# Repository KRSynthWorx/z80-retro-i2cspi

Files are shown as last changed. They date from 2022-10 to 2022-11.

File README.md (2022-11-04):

# [Z80-Retro!](https://github.com/johnwinans/2063-Z80) I2C/SPI Master Interface Board & Driver Library

An addon I2C/SPI master interface board that uses the [Z80-Retro!](https://github.com/johnwinans/2063-Z80)
parallel printer port and a bit-banged driver library to interact
with the I2C/SPI ports. KiCad design files are also included.

## Description

### Driver Library
[i2cspi_lib.asm](src/i2cspi_lib.asm) -
This driver library includes all necessary routines to communicate with I2C and SPI hardware devices
using the Z80-Retro! parallel port. Extensive comments and protocol descriptions are provided
to help understand the library. The library requires the [retromon.sym](https://github.com/KRSynthWorx/z80-retro-monitor/blob/main/src/retromon.sym)
symbol table from the [z80-retro-monitor](https://github.com/KRSynthWorx/z80-retro-monitor) project.

### PCB Hardware
An I2C/SPI master interface board using bit-bang techniques and utilizes the Z80-Retro!
parallel printer port. The PCB design includes 4 I2C ports and 4 SPI ports. The I2C
ports are all common and the SPI ports include 4 individual chip select (CS) lines.
Requires +5vdc be connected from the Z80-Retro! or an external power supply.

* A PDF version of the schematic can be found [here](kicad/i2c-adapter-schematic.pdf).

### PCB Layout

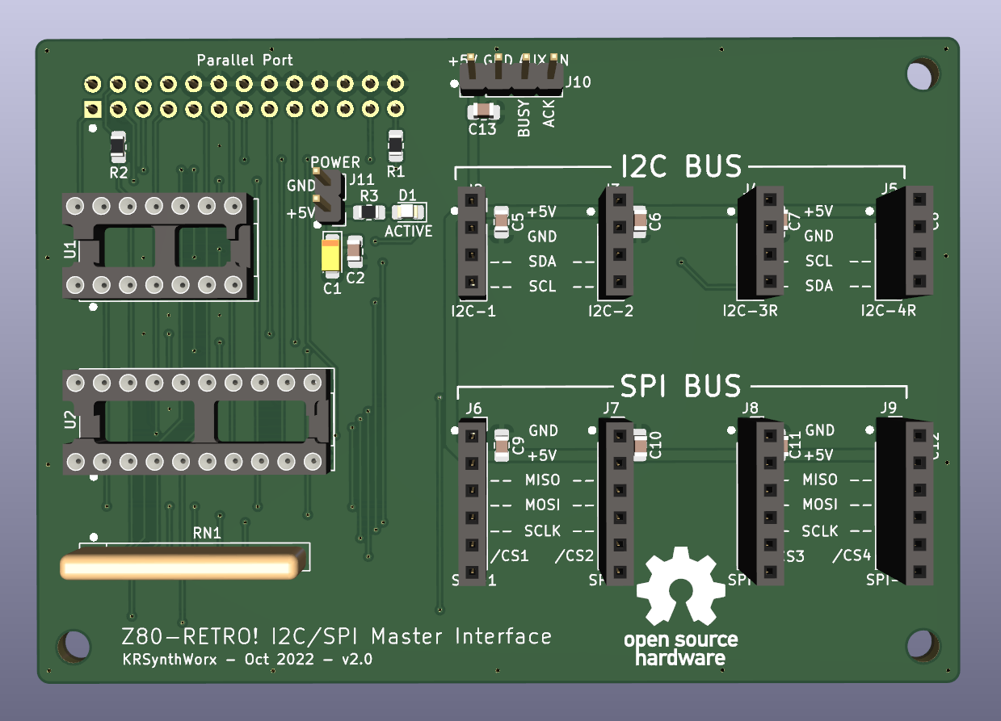
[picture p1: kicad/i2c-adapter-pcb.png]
PC Board Image I2C/SPI Master Interface Board


---

### I2C Timing Capture

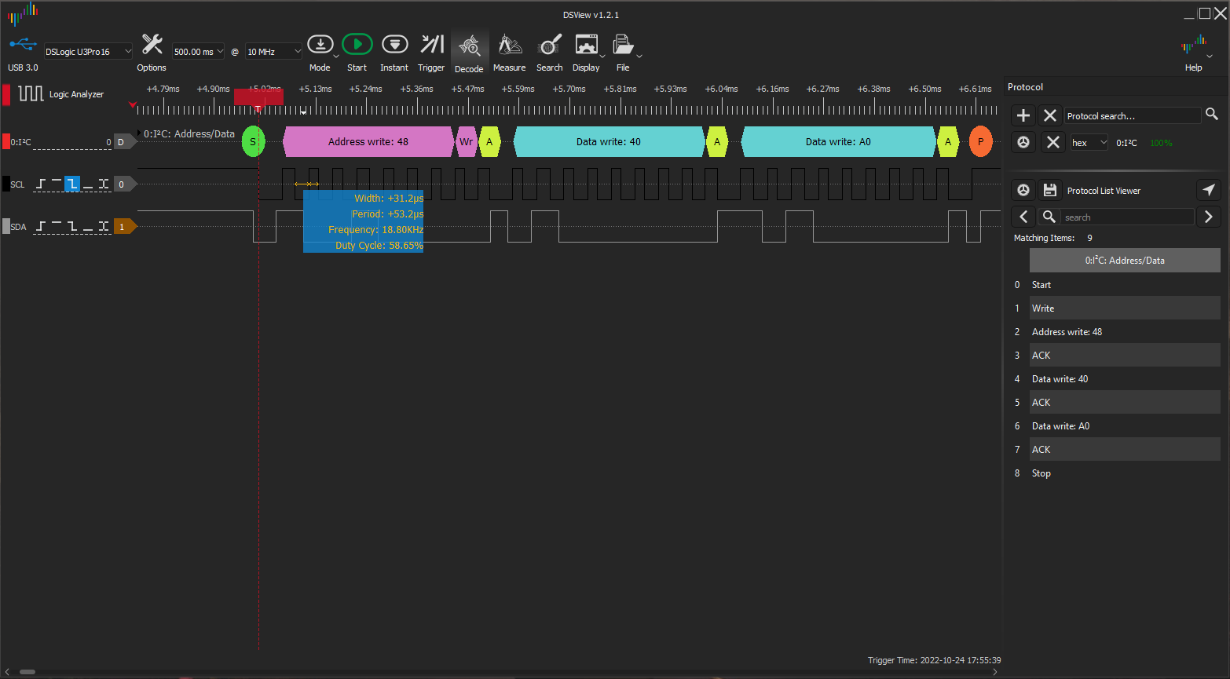
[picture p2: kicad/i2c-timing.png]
I2C Timing I2C Logic Analyzer Write Timing


---

### SPI Timing Capture
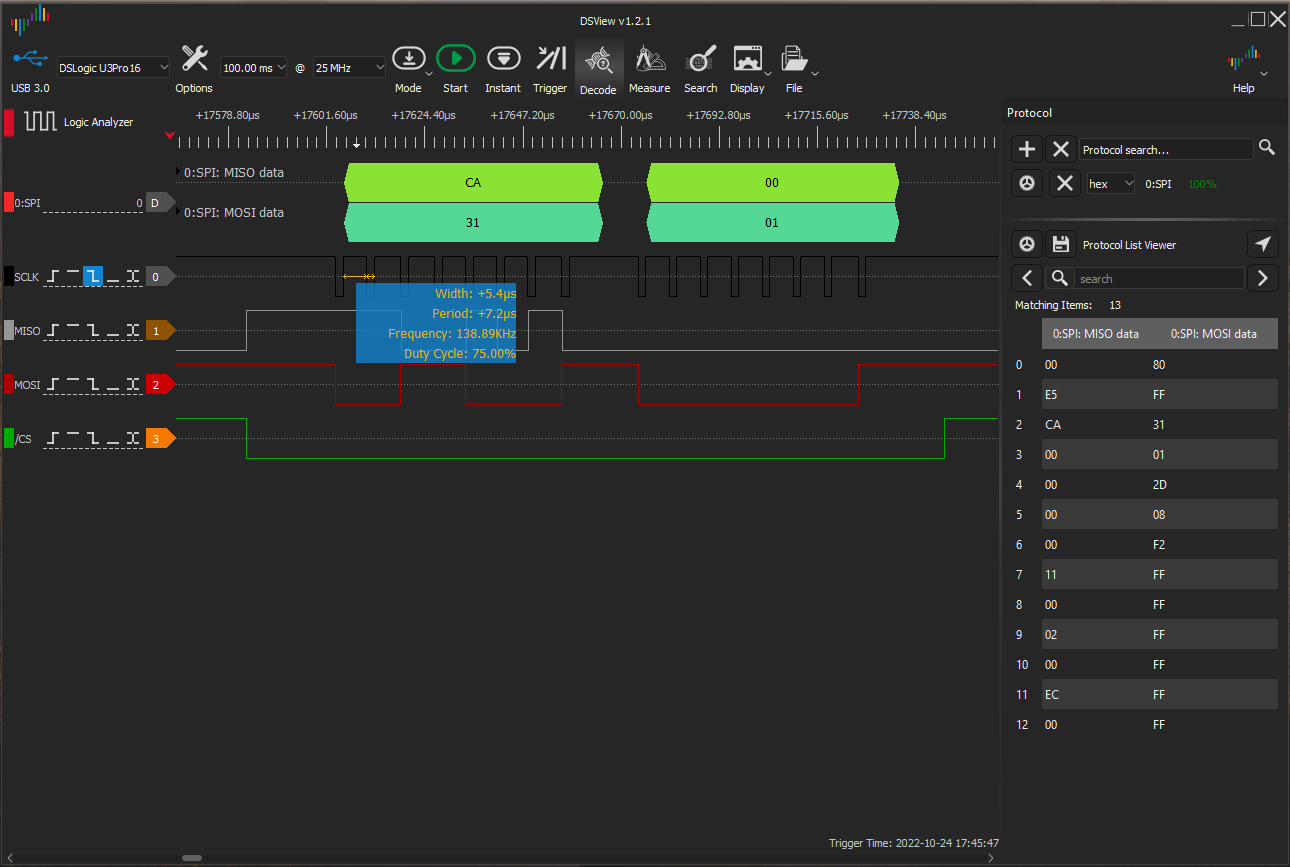
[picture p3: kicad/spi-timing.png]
SPI Timing SPI Logic Analyzer Write Timing


## Help

### Library Common Routines

```ACTIVE_LED``` - Set the ACTIVE LED on the I2C/SPI interface board on or off  

---

### I2C Routines

```I2C_INIT``` - Initialize I2C status variables and the Z80-Retro! PRN_DAT port  
```I2C_START``` - Initiate I2C communication with a START condition  
```I2C_STOP``` - Stop I2C communication with a STOP condition  
```I2C_SEND_BIT``` - Send a bit over the I2C bus  
```I2C_READ_BIT``` - Read a bit on the I2C bus  
```I2C_SEND_BYTE``` - Send a byte to the I2C bus  
```I2C_READ_BYTE``` - Read a byte from the I2C bus  
```I2C_SEND_STREAM``` - Send a byte stream to the I2C bus  
```I2C_READ_STREAM``` - Read a byte stream from the I2C bus  

---

### SPI Routines

```SPI_INIT```- Initialize the SPI MODE, bit transfer order and the Z80-Retro! PRN_DAT port  
```SPI_SEND_BYTE``` - Send 8 bits to the SPI port and discard the received data  
```SPI_READ_BYTE``` - Read 8 bits from the SPI port  
```SPI_CSx_TRUE``` - Assert the select line initialized in SPI_INIT (CS1 - CS4) supported  
```SPI_CSx_FALSE``` - De-assert the select line initialized in SPI_INIT (CS1 - CS4) supported  
```SPI_SEND_STREAM``` - Send a stream of bytes to the SPI port  
```SPI_READ_STREAM``` - Read a stream of bytes from the SPI port  

---

Several example routines are included to test the various functions. Everything is heavily
commented explaining the library routines and how to use them. These include:
- [ad_test.asm](src/ad_test.asm) - test a NXP Semiconductors PCF8591 I2C A/D-D/A converter
- [eeprom_test.asm](src/eeprom_test.asm) - test a generic 24C256 I2C EEPROM
- [gpio_test.asm](src/gpio_test.asm) - test a NXP Semiconductors PCF8574 I2C 8-bit GPIO expander
- [led_test.asm](src/led_test.asm) - test an Analog Devices MAX7219 LED driver in SPI mode 0
- [oled_test.asm](src/oled_test.asm) - test a generic SSD1306 128x64 SPI 0.96" OLED display
- [spi_test.asm](src/spi_test.asm) - test an Analog Devices ADXL345 accelerometer in SPI mode 3

## Author

[Kenny Maytum](mailto:ken_m@comcast.net) - KRSynthWorx

## Version History

* v1.0 - Driver Library
	* Initial Public Release
* v2.0 - KiCad Design Files
	* Initial Public Release

## License

This project is licensed under the [GNU Lesser General Public License] - see the LICENSE file for details

## Acknowledgments

Inspiration, code snippets, libraries, etc.
* [John's Basement YouTube Channel](https://www.youtube.com/c/JohnsBasement)
* [John Winans](https://github.com/johnwinans)
* [K. S. Jiang](https://github.com/ksjiang/bb85)
* [I2C Bus](https://i2c-bus.org)
* [SPI Bus](https://www.corelis.com/education/tutorials/spi-tutorial)

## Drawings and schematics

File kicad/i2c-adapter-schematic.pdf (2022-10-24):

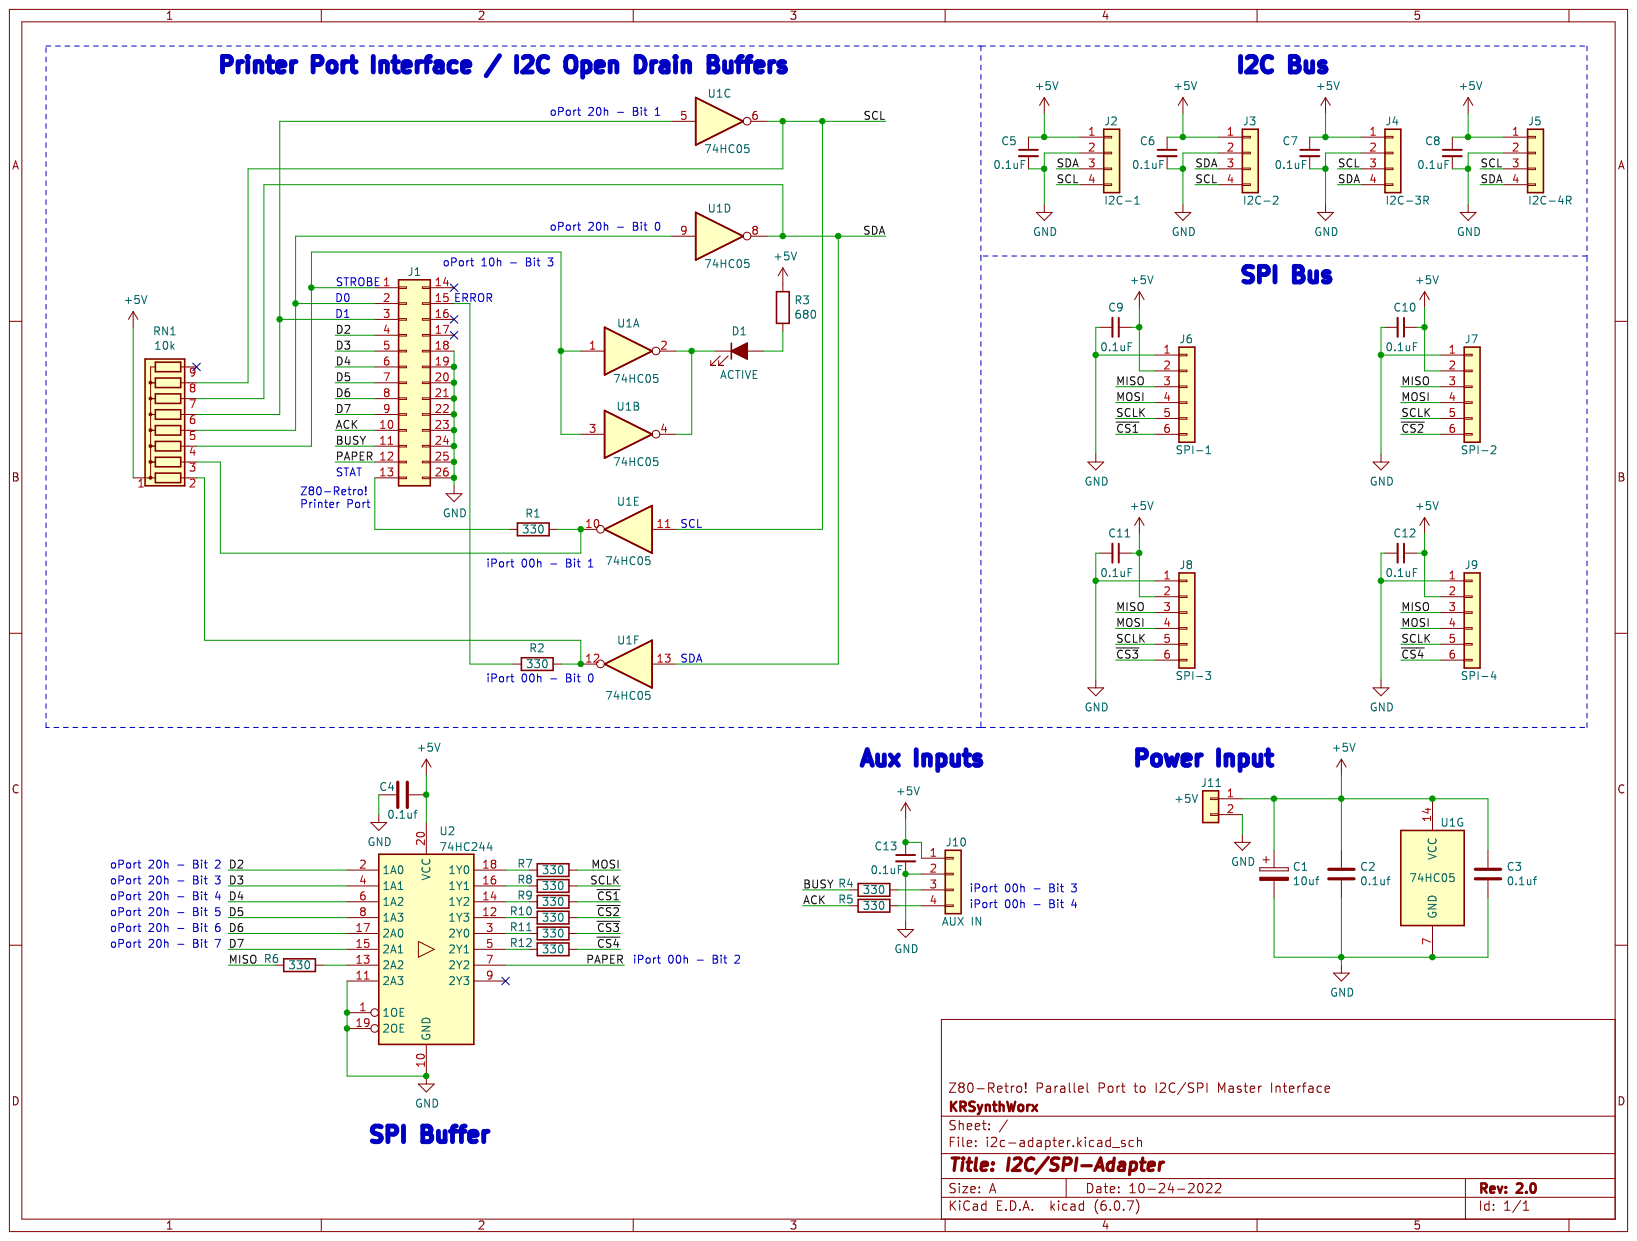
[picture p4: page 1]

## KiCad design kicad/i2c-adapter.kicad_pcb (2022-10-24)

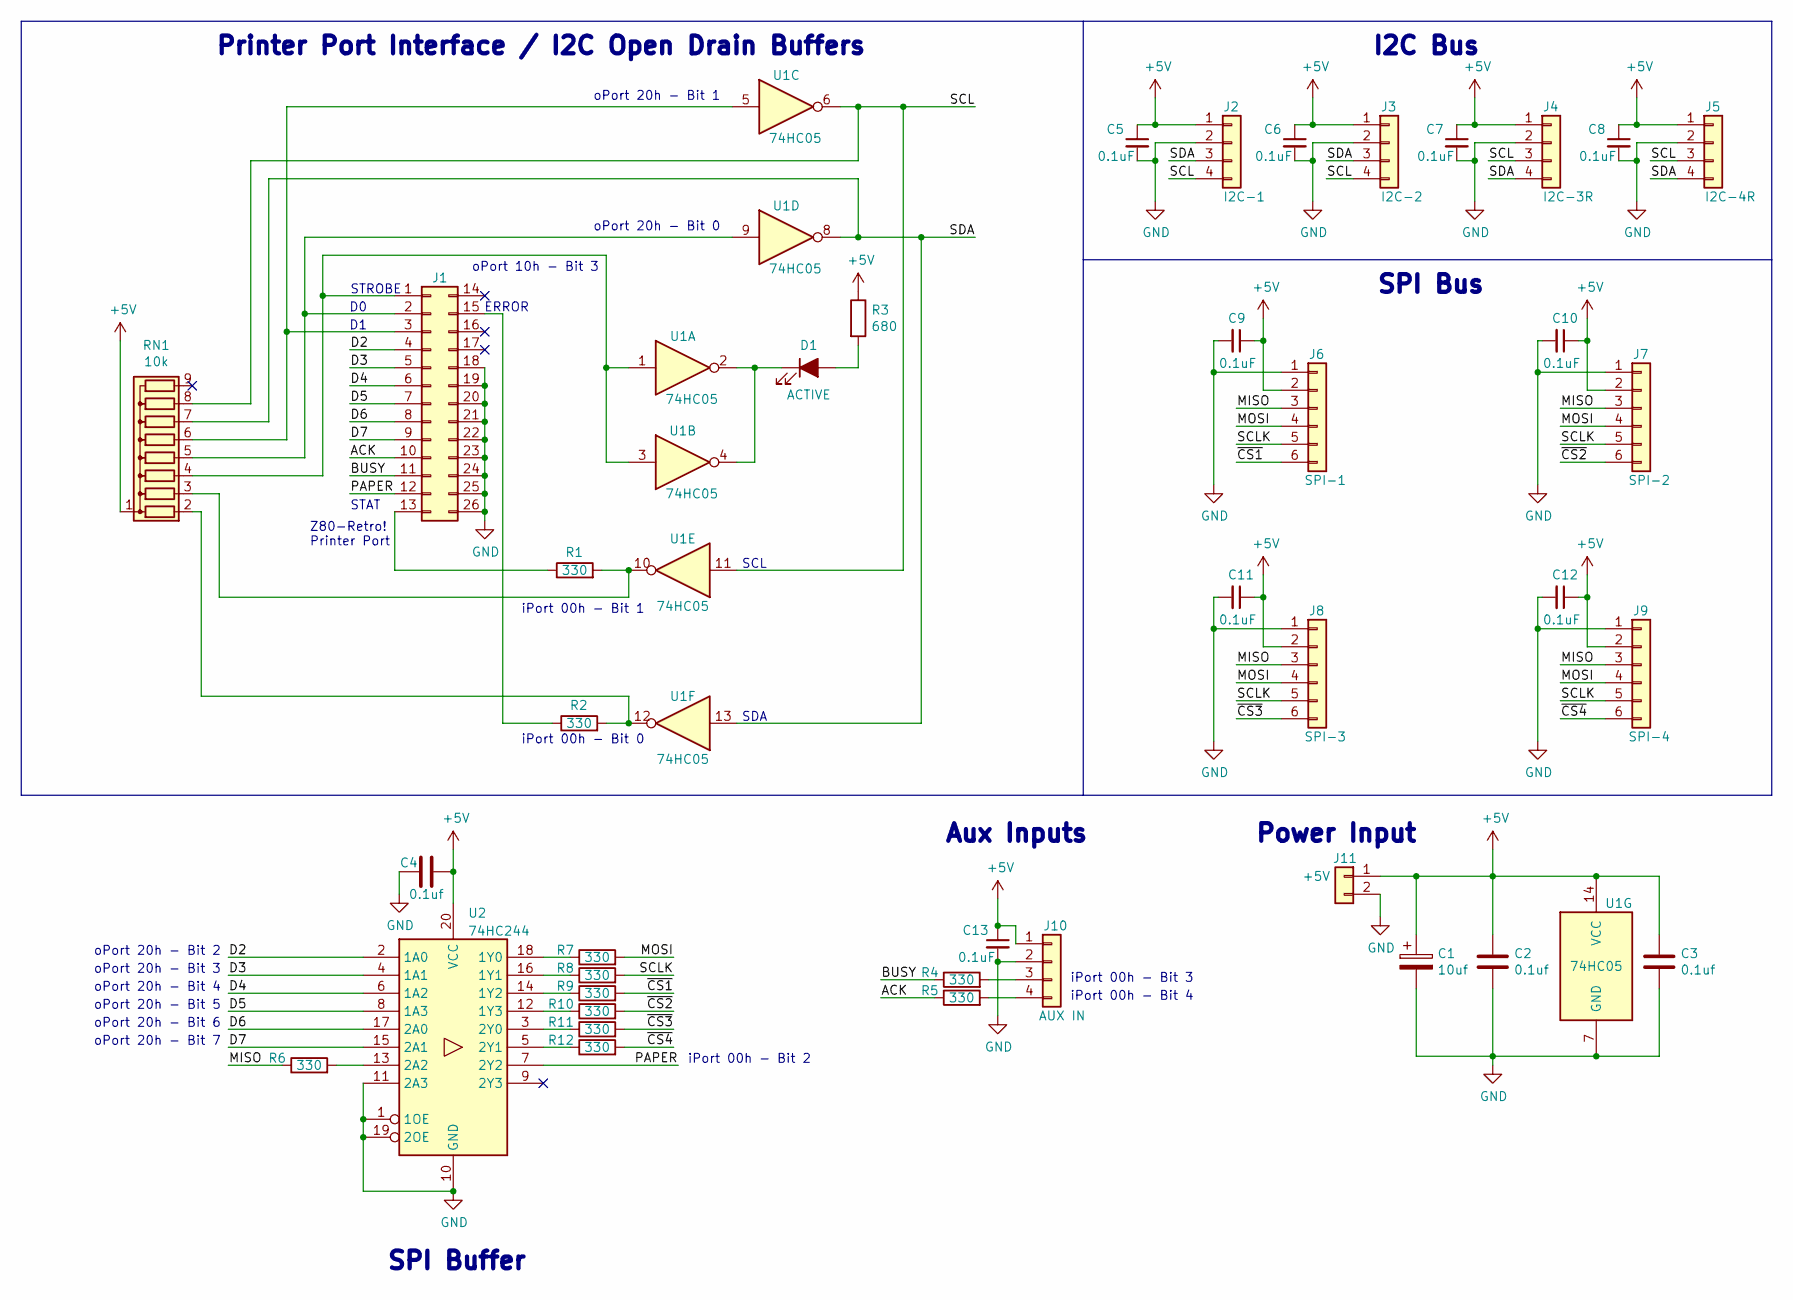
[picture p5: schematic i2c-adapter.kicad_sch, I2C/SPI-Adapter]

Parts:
C1: 10uf; CP_EIA-3216-10_Kemet-I_Pad1.58x1.35mm_HandSolder
C2, C3, C4: 0.1uf; C_0805_2012Metric_Pad1.18x1.45mm_HandSolder
C5, C6, C7, C8, C9, C10, C11, C12, C13: 0.1uF; C_0805_2012Metric_Pad1.18x1.45mm_HandSolder
D1: ACTIVE; LED_0805_2012Metric_Pad1.15x1.40mm_HandSolder
J1: Conn_02x13_Top_Bottom; PinSocket_2x13_P2.54mm_Vertical_clockwise
J2: I2C-1; PinSocket_1x04_P2.54mm_Vertical
J3: I2C-2; PinSocket_1x04_P2.54mm_Vertical
J4: I2C-3R; PinSocket_1x04_P2.54mm_Vertical
J5: I2C-4R; PinSocket_1x04_P2.54mm_Vertical
J6: SPI-1; PinSocket_1x06_P2.54mm_Vertical
J7: SPI-2; PinSocket_1x06_P2.54mm_Vertical
J8: SPI-3; PinSocket_1x06_P2.54mm_Vertical
J9: SPI-4; PinSocket_1x06_P2.54mm_Vertical
J10: AUX IN; PinHeader_1x04_P2.54mm_Vertical
J11: +5V; PinHeader_1x02_P2.54mm_Vertical
R1, R2, R4, R5, R6, R7, R8, R9, R10, R11, R12: 330; R_0805_2012Metric_Pad1.20x1.40mm_HandSolder
R3: 680; R_0805_2012Metric_Pad1.20x1.40mm_HandSolder
RN1: 10k; R_Array_SIP9
U1: 74HC05; DIP-14_W7.62mm_Socket
U2: 74HC244; DIP-20_W7.62mm_Socket

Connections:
+5V: C1.1, C2.1, C3.1, C4.1, C5.1, C6.1, C7.1, C8.1, C9.1, C10.1, C11.1, C12.1, C13.1, J2.1, J3.1, J4.1, J5.1, J6.2, J7.2, J8.2, J9.2, J10.1, J11.1, R3.1, RN1.1 (common), U1.14 (VCC), U2.20 (VCC)
/ACK: J1.10, R5.1
/BUSY: J1.11, R4.1
/D2: J1.4, U2.2 (1A0)
/D3: J1.5, U2.4 (1A1)
/D4: J1.6, U2.6 (1A2)
/D5: J1.7, U2.8 (1A3)
/D6: J1.8, U2.17 (2A0)
/D7: J1.9, U2.15 (2A1)
/MISO: J6.3, J7.3, J8.3, J9.3, R6.1
/MOSI: J6.4, J7.4, J8.4, J9.4, R7.2
/PAPER: J1.12, U2.7 (2Y2)
/SCL: J2.4, J3.4, J4.3, J5.3, RN1.8 (R7), U1.6, U1.11
/SCLK: J6.5, J7.5, J8.5, J9.5, R8.2
/SDA: J2.3, J3.3, J4.4, J5.4, RN1.7 (R6), U1.8, U1.13
/~CS1: J6.6, R9.2
/~CS2: J7.6, R10.2
/~CS3: J8.6, R11.2
/~CS4: J9.6, R12.2
GND: C1.2, C2.2, C3.2, C4.2, C5.2, C6.2, C7.2, C8.2, C9.2, C10.2, C11.2, C12.2, C13.2, J1.18, J1.19, J1.20, J1.21, J1.22, J1.23, J1.24, J1.25, J1.26, J2.2, J3.2, J4.2, J5.2, J6.1, J7.1, J8.1, J9.1, J10.2, J11.2, U1.7 (GND), U2.1 (1OE), U2.10 (GND), U2.11 (2A3), U2.19 (2OE)
unnamed: D1.1 (K), U1.2, U1.4
unnamed: D1.2 (A), R3.2
unnamed: J1.1, RN1.4 (R3), U1.1, U1.3
unnamed: J1.2, RN1.5 (R4), U1.9
unnamed: J1.3, RN1.6 (R5), U1.5
unnamed: J1.13, R1.1
unnamed: J1.15, R2.1
unnamed: J10.3, R4.2
unnamed: J10.4, R5.2
unnamed: R1.2, RN1.3 (R2), U1.10
unnamed: R2.2, RN1.2 (R1), U1.12
unnamed: R11.1, U2.3 (2Y0)
unnamed: R12.1, U2.5 (2Y1)
unnamed: R10.1, U2.12 (1Y3)
unnamed: R6.2, U2.13 (2A2)
unnamed: R9.1, U2.14 (1Y2)
unnamed: R8.1, U2.16 (1Y1)
unnamed: R7.1, U2.18 (1Y0)

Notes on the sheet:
iPort 00h - Bit 0
oPort 20h - Bit 3
oPort 20h - Bit 5
oPort 20h - Bit 1
oPort 20h - Bit 0
oPort 10h - Bit 3
Printer Port Interface / I2C Open Drain Buffers
Z80-Retro! Printer Port
oPort 20h - Bit 2
ERROR
oPort 20h - Bit 7
oPort 20h - Bit 6
STAT
I2C Bus
oPort 20h - Bit 4
SCL
Power Input
Aux Inputs
iPort 00h - Bit 4
iPort 00h - Bit 3
iPort 00h - Bit 2
SDA
SPI Bus
STROBE
SPI Buffer
iPort 00h - Bit 1

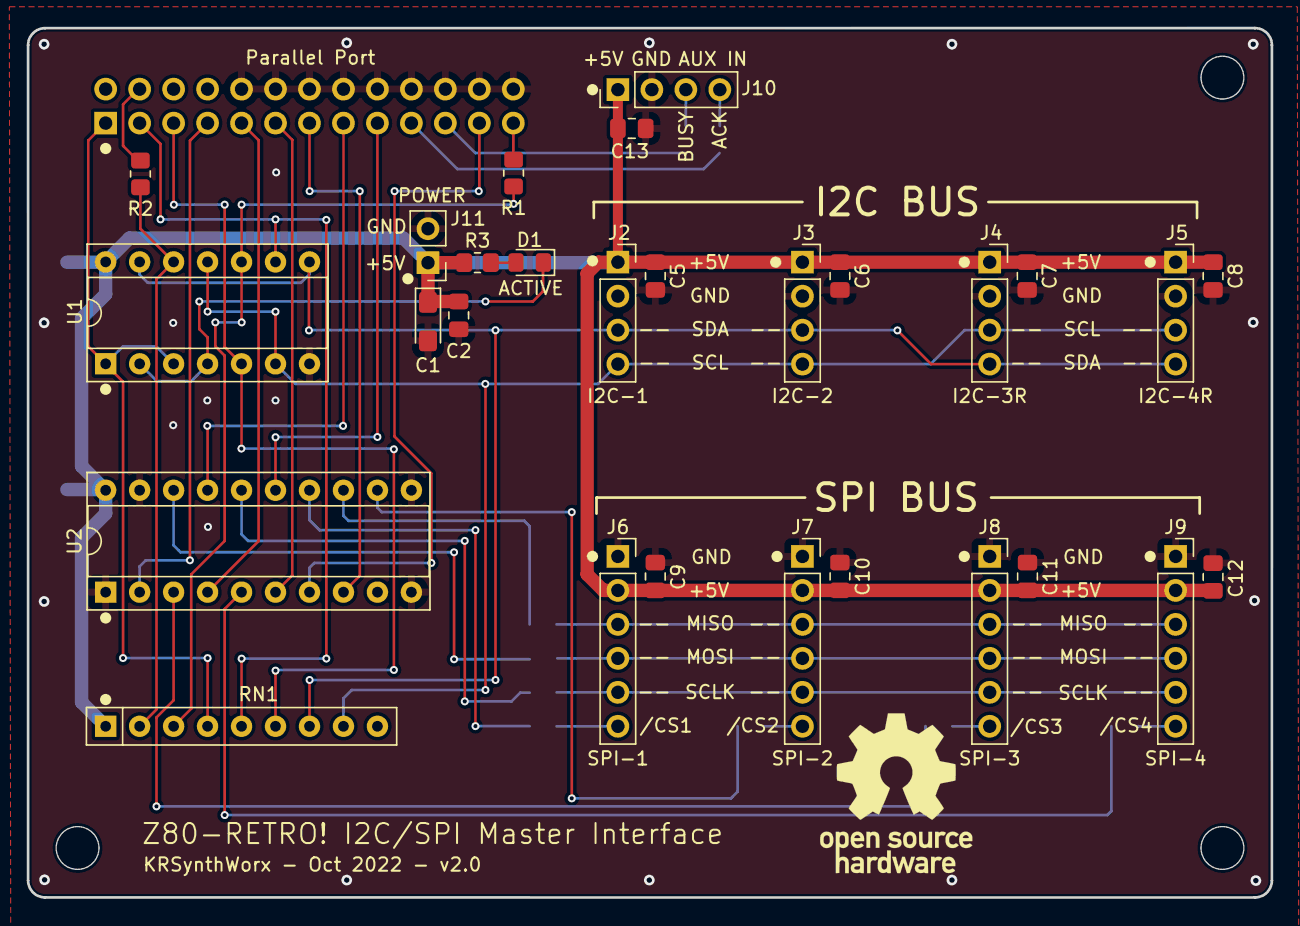
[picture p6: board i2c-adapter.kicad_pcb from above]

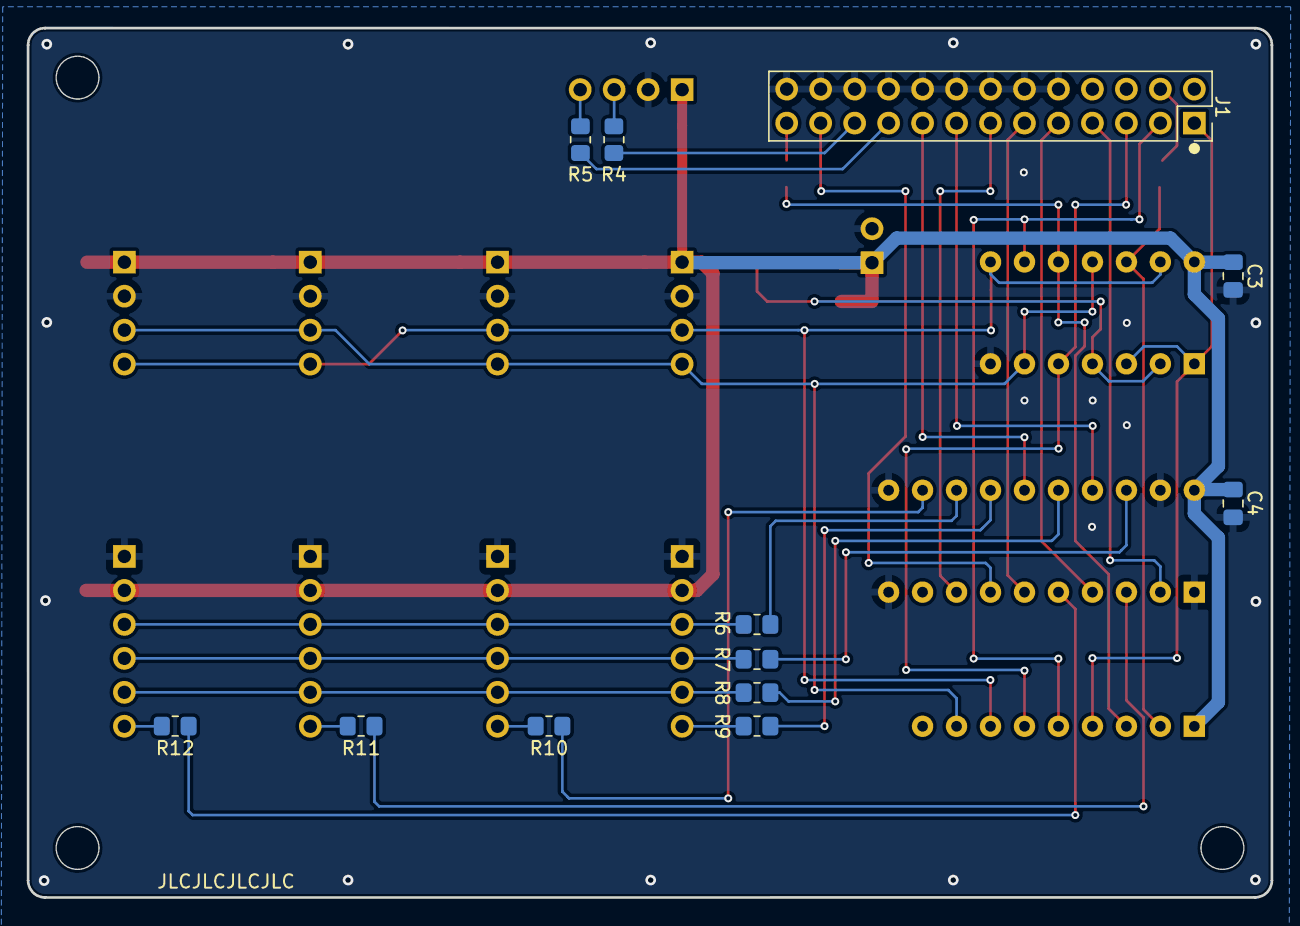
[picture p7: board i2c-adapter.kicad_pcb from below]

Board: 2 copper layers, 93.0 x 65.0 mm, 40 parts (12 on the bottom side), 38 nets.

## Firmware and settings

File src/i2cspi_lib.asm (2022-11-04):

;***********************************************************************************************************************
;
;						Z 8 0 - R E T R O !  I 2 C / S P I  B I T - B A N G  L I B R A R Y
;
;***********************************************************************************************************************
;	i2cspi_lib.asm v1.0 - an I2C/SPI master library for the <jb> Z80 Retro! SBC
;	Kenny Maytum - KRSynthWorx - October 24th, 2022
;***********************************************************************************************************************

;***********************************************************************************************************************
;								I 2 C / S P I  L I B R A R Y  L I C E N S E S
;***********************************************************************************************************************
;
;	This I2C library...
;
;	Copyright (C) 2022 Kenny Maytum - https://github.com/KRSynthWorx/z80-retro-i2cspi
;
;	This library is free software; you can redistribute it and/or
;	modify it under the terms of the GNU Lesser General Public
;	License as published by the Free Software Foundation; either
;	version 2.1 of the License, or (at your option) any later version.
;
;	This library is distributed in the hope that it will be useful,
;	but WITHOUT ANY WARRANTY; without even the implied warranty of
;	MERCHANTABILITY or FITNESS FOR A PARTICULAR PURPOSE. See the GNU
;	Lesser General Public License for more details.
;
;	You should have received a copy of the GNU Lesser General Public
;	License along with this library; if not, write to the Free Software
;	Foundation, Inc., 51 Franklin Street, Fifth Floor, Boston, MA
;	02110-1301 USA
;
;	https://www.gnu.org/licenses/old-licenses/lgpl-2.1.html
;
;-----------------------------------------------------------------------------------------------------------------------
;
;	Portions of the SPI library algorithm provided by John Winans ...
;
;	Copyright (C) 2021,2022 John Winans - https://github.com/johnwinans/2063-Z80-cpm
;
;	This library is free software; you can redistribute it and/or
;	modify it under the terms of the GNU Lesser General Public
;	License as published by the Free Software Foundation; either
;	version 2.1 of the License, or (at your option) any later version.
;
;	This library is distributed in the hope that it will be useful,
;	but WITHOUT ANY WARRANTY; without even the implied warranty of
;	MERCHANTABILITY or FITNESS FOR A PARTICULAR PURPOSE. See the GNU
;	Lesser General Public License for more details.
;
;	You should have received a copy of the GNU Lesser General Public
;	License along with this library; if not, write to the Free Software
;	Foundation, Inc., 51 Franklin Street, Fifth Floor, Boston, MA
;	02110-1301 USA
;
;	https://www.gnu.org/licenses/old-licenses/lgpl-2.1.html
;
;-----------------------------------------------------------------------------------------------------------------------
;
;	Portions of the I2C bit-bang algorithm provided by K. S. Jiang ...
;
;	The MIT License
;
;	Copyright (C) 2018 siyujiang81 - https://github.com/ksjiang/bb85
;
;	Permission is hereby granted, free of charge, to any person obtaining a copy
;	of this software and associated documentation files (the "Software"), to deal
;	in the Software without restriction, including without limitation the rights
;	to use, copy, modify, merge, publish, distribute, sublicense, and/or sell
;	copies of the Software, and to permit persons to whom the Software is
;	furnished to do so, subject to the following conditions:
;
;	The above copyright notice and this permission notice shall be included in all
;	copies or substantial portions of the Software.
;
;	THE SOFTWARE IS PROVIDED "AS IS", WITHOUT WARRANTY OF ANY KIND, EXPRESS OR
;	IMPLIED, INCLUDING BUT NOT LIMITED TO THE WARRANTIES OF MERCHANTABILITY,
;	FITNESS FOR A PARTICULAR PURPOSE AND NONINFRINGEMENT. IN NO EVENT SHALL THE
;	AUTHORS OR COPYRIGHT HOLDERS BE LIABLE FOR ANY CLAIM, DAMAGES OR OTHER
;	LIABILITY, WHETHER IN AN ACTION OF CONTRACT, TORT OR OTHERWISE, ARISING FROM,
;	OUT OF OR IN CONNECTION WITH THE SOFTWARE OR THE USE OR OTHER DEALINGS IN THE
;	SOFTWARE.
;
;	https://mit-license.org/
;
;***********************************************************************************************************************

;***********************************************************************************************************************
;										A C K N O W L E D G E M E N T S
;***********************************************************************************************************************
;
;	Many thanks to John Winans and his Z80-Retro! SBC projects.
;
;	Z80-Retro! project:	https://github.com/johnwinans/2063-Z80
;	FLASH programmer:	https://github.com/johnwinans/2065-Z80-programmer
;	CP/M BIOS project:	https://github.com/johnwinans/2063-Z80-cpm
;
;	John's Basement <jb> YouTube Channel:
;	https://www.youtube.com/c/JohnsBasement
;
;***********************************************************************************************************************
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

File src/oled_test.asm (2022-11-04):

;--------------------------------------------------------------------------
; oled_test.asm - routine to test the SSD1306 SPI 128x64 0.96" OLED display
; Kenny Maytum - KRSynthWorx - November 4th, 2022
;--------------------------------------------------------------------------

;--------------------------------------------------------------------------
; The display used in this test routine, configured for 4-wire SPI:
; https://www.buydisplay.com/yellow-blue-0-96-inch-oled-display-breakout-board-library-for-arduino
;
; The SSD1306 datasheet is here:
; https://www.buydisplay.com/download/ic/SSD1306.pdf
;
; These are also available on eBay and Amazon, just insure that they are
; the 7-pin version and are configured for 4-wire SPI.
;
; These SSD1306 displays are 3.3 vdc only but include a 5 vdc to 3.3 vdc
; voltage regulator so we can power them from the Z80-Retro! I2C/SPI
; interface board +5 vdc source. Care must be taken with the signal lines
; though. You can put together a simple resistor voltage divider as
; shown below. We don't need to read anything from the display (you can't
; in serial mode anyway), so we don't need any active level shifters.
;
; Z80-Retro! I2C/SPI
; Interface Board Pins
;         |
;         |
;                   ________                     ________
;       SCLK ->____|  2.7K  |_._________________|  4.7K  |_____ 
;                  |________| |                 |________|     |
;                             |                                |
;                   ________  |                  ________      |
;       MOSI ->____|  2.7K  |_|___._____________|  4.7K  |_____.
;                  |________| |   |             |________|     |
;                             |   |                            |
;                   ________  |   |              ________      |
;       /CS3 ->____|  2.7K  |_|___|___._________|  4.7K  |_____.
;                  |________| |   |   |         |________|     |
;                             |   |   |                        |
;                   ________  |   |   |          ________      |
;       /CS2 ->____|  2.7K  |_|___|___|___._____|  4.7K  |_____.
;                  |________| |   |   |   |     |________|     |
;                             |   |   |   |                    |
;                   ________  |   |   |   |      ________      |
;       /CS1 ->____|  2.7K  |_|___|___|___|___._|  4.7K  |_____.
;                  |________| |   |   |   |   | |________|     |
;        +5  ->___________    |   |   |   |   |                |
;                         |   |   |   |   |   |                |
;        GND ->_______.___|___|___|___|___|___|________________|
;                     |   |   |   |   |   |   |
;                _____|___|___|___|___|___|___|_____
;               |    GND +5  D0  D1  RES DC  CS     |
;               |                                   |
;               |          SSD1306 Display          |
;               |          0.96" SPI OLED           |
;               |           128x64 Pixels           |
;               |                                   |
;               |___________________________________|
;
; To help with performance, we use a spare (/CS2) line from the interface
; to toggle the Data/Command# line instead of configuring 3-wire SPI and
; sending the DC command in software on each command or data byte
; transferred. We also use a spare (/CS3) line to be able to remotely
; reset the display from the Z80-Retro! The MISO input line on the
; interface board is not used.
;--------------------------------------------------------------------------

; Misc equates
.SPI_DC:	EQU	0x20			; Display DC pin Data/Command# use SPI /CS2 output
.SPI_RES:	EQU	0x40			; Display RES pin Reset use SPI /CS3 output
.BUF_LEN:	EQU	128*8			; Size of screen character buffer

	ORG		0x1000

	CALL	DSPMSG
	DEFB	CR,LF,LF,'Z80-Retro! I2C/SPI Master Interface test routine',CR,LF
	DEFB	'Test a SSD1306 128x64 0.96" SPI OLED display..',BIT7+'.'

	CALL	CRLF
	CALL	CRLF
	LD		A,CS1|MSB_LSB|MODE0	; /CS1 active, MSB->LSB bit order
								; SPI MODE (CPOL = 0, CPHA = 0)
	CALL	SPI_INIT			; Initialize the SPI port with these values
	CALL	SSD1306_RESET		; Toggle RES pin

; Send a string of commands to initialize the display
	LD		C,0xA1				; Segment re-map direction, 0xA0 normal, 0xA1 reverse
	CALL	SSD1306_CMD

	LD		C,0xC8				; Common output scan direction 0xC0 - 0xC8
	CALL	SSD1306_CMD

	LD		C,0x81				; Contrast level byte one 0x81
	CALL	SSD1306_CMD

	LD		C,0x7F				; Contrast level byte two 0x00 - 0xFF
	CALL	SSD1306_CMD

	LD		C,0xA6				; 0xA6 normal display, 0xA7 reverse display
	CALL	SSD1306_CMD

	LD		C,0x8D				; Enable charge pump regulator byte one 0x8D
	CALL	SSD1306_CMD

	LD		C,0x14				; Enable charge pump regulator byte two 0x14
	CALL	SSD1306_CMD

	LD		C,0xAF				; 0xAE display off (sleep), 0xAF display on
	CALL	SSD1306_CMD

	LD		C,0x20				; Memory address mode byte one 0x20
	CALL	SSD1306_CMD

	LD		C,0x00				; Memory address mode byte two 0x00 = horizontal
	CALL	SSD1306_CMD

; Clear the entire screen
	CALL	SSD1306_CLEAR

	CALL	DSPMSG				; Status message on main console
	DEFB	'-> Displaying 1st screen on SSD1306 now..',BIT7+'.'
	
; Display static text on SSD1306 defined just past the function call
	CALL	DSP_TXT
	DEFB	'Static text...',CR,LF,LF				; Extra LF for a blank line
	DEFB	' !"#$%&',0x27,'()*+,-./01234',CR,LF	; 0x27 = '
	DEFB	'56789:;<=>?@ABCDEFGHI',CR,LF
	DEFB	'JKLMNOPQRSTUVWXYZ[',0x5C,']^',CR,LF	; 0x5C = '\'
	DEFB	'_`abcdefghijklmnopqrs',CR,LF
	DEFB	'tuvwxyz{|}~',0x7F,CR,LF,LF				; 0x7F = DEL, last LF causes wrap to top
	DEFB	'2.5 sec delay...',CR,BIT7+LF			; <-- Terminate string with MSB set

	CALL	DSPMSG				; Status message on main console
	DEFB	CR,LF,'-> 2.5 second delay on SSD1306 now..',BIT7+'.'
	
	LD		D,0xFF				; 2550ms delay
	CALL	DELAY_10MS
	CALL	SSD1306_CLEAR
	
	CALL	DSPMSG				; Status message on main console
	DEFB	CR,LF,'-> Displaying 2nd screen on SSD1306 now..',BIT7+'.'

; Display buffer text on SSD1306 pointed to by HL
	LD		HL,.TXT_BUF
	CALL	DSP_BUF

.SUCCESS:
	CALL	DSPMSG				; Status message on main console
	DEFB	CR,LF,LF,'Test complete',BIT7+'!'

	CALL	CRLF
	JP		START				; Return to monitor

; Sample text buffer
.TXT_BUF:	DEFB	'From a buffer...',CR,LF,LF		; Extra LF for a blank line
			DEFB	'Greetings from the',CR,LF
			DEFB	'Z80-Retro! SBC',CR,LF,LF		; Extra LF for a blank line
			DEFB	'* * * * * * * * * * *',CR,LF
			DEFB	'Thank you John Winans',CR,LF
			DEFB	'* * * * * * * * * * ',BIT7+'*'	; <-- Terminate buffer with MSB set

;-------------------------------------------------------------------------
; DSP_TXT
; Displays a static text string defined just past the call to this function
; Includes a 100ms delay to slow the display of characters
;
; Input: Gets address of string from stack. EOL = MSB (bit 7) set
; Return: none
; Destroys: A, BC, DE, HL	
;--------------------------------------------------------------------------
DSP_TXT:
	POP		HL					; Get address of string
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

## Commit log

2022-10-24 Inital commit
    [i2c-adapter.kicad_pcb, i2c-adapter.kicad_sch]
2022-10-27 Add LED test example
2024-04-21 Add OLED display test example
    [i2c-adapter.kicad_pcb, i2c-adapter.kicad_sch]
